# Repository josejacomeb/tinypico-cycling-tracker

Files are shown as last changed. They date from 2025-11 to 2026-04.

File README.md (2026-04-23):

# tinypico-cycling-tracker

Tinypico based GPS + IMU + SD data logger for cycling purposes
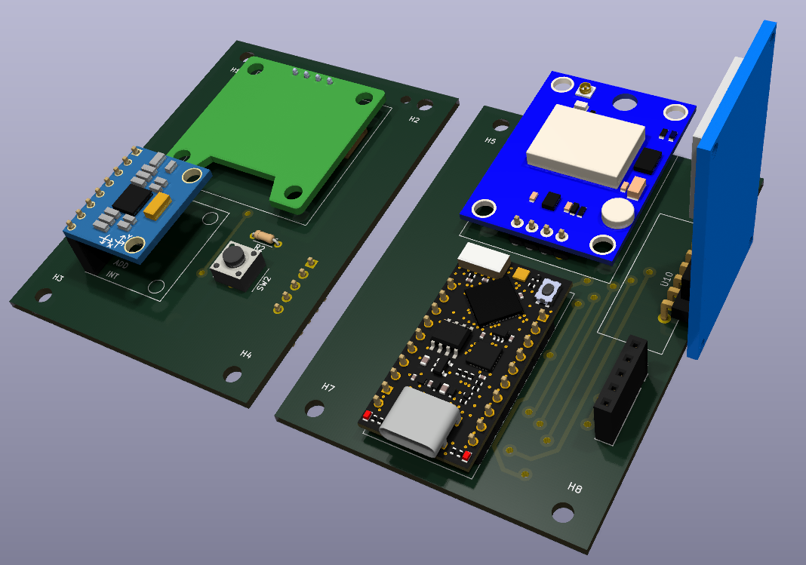
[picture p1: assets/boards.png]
TinyPico Cycling Tracker TinyPICO Cycling Tracker


## Components

### Software

**Programming Languages**: C++20 and Python 3.12

#### Electronic Design

- [Kicad v9.x.x](https://www.kicad.org/)
- [KiKit v1.7.x](https://yaqwsx.github.io/KiKit/latest/)

#### Integrated Development Environment

- [Arduino IDE v2.3.x](https://www.arduino.cc/en/software/)
- [Visual Studio Code](https://code.visualstudio.com/)

#### Software Libraries

- [TinyGPS++](https://github.com/mikalhart/TinyGPSPlus)
- [Electronics Cats MPU6050](https://github.com/ElectronicCats/mpu6050)
- [Embedded_UKF_Library](https://github.com/pronenewbits/Embedded_UKF_Library)
- [Pandas 2.x](https://pandas.pydata.org/)
- [gpxpy](https://github.com/tkrajina/gpxpy)
- [FilterPy v1.4.x](https://filterpy.readthedocs.io/en/latest/#)

### Hardware

- [TinyPICO](https://www.tinypico.com/): An ESP32 Dico D4 based development platform
- [uBlox-Neo6M](https://www.u-blox.com/en/product/neo-6-series): A versatile GPS Module with Antenna
- [Display OLED I2C 0.96" SSD1306](https://soldered.com/product/display-oled-i2c-white-0-96-ssd1306/): An 128x64px 0.96" OLED Display with I2C Communication
- [MPU6050](https://invensense.tdk.com/products/motion-tracking/6-axis/mpu-6050/): An integrated gyroscope and accelerometer with I2C communication
- [MicroSD Card Adapter](https://hobbycomponents.com/adapters/578-microsd-card-adapter-with-level-shifters): A SPI module to interface microcontrollers with a microSD card.

### Communication Protocols

- SPI: SD Card Reader -> TinyPICO
- I2C: OLED Screen & MPU6050 -> TinyPICO
- UART: GPS -> TinyPICO

## Instructions

### For KiCad

1. Add the symbols via the `Preferences` > `Manage symbol Libraries` > `Project Specific Libraries`, make sure that you add the `kicad-libraries` subfolders:

    1. `usini_kicad_sensors/usini_sensors.pretty`
    2. `uBlox-Neo6M/uBLox-NEO-6M.pretty`
    3. `MicroSD-Card-Adapter/MicroSD-Card-Adapter.kicad_sym`
    4. `Soldered-SSD1306-OLED-Display/Soldered.kicad_sym`
    5. `TinyPICO/TinyPICO.kicad_sym`

2. Add the footprints via the `Preferences` > `Manage Footprint Libraries` > `Project Specific Libraries`, make sure that you add the `footprint` subfolders
    1. `usini_kicad_sensors/usini_sensors.kicad_sym`
    2. `uBlox-Neo6M/uBlox-NEO-6M.kicad_sym`
    3. `MicroSD-Card-Adapter/MicroSD-Card-Adapter.kicad_sym`
    4. `Soldered-SSD1306-OLED-Display/Soldered.pretty`
    5. `TinyPICO/TinyPICO.pretty`

3. Install the `KiKit` in your local system

    ```bash
    python -m venv .venv/
    source .venv/bin/activate
    pip3 install kikit
    ```

### For Arduino

#### Run the full prototype

1. Please follow the Espressif [instructions](https://docs.espressif.com/projects/arduino-esp32/en/latest/installing.html) to support the `ESP32` boards on your Arduino.
2. Please install the following libraries in your Arduino IDE in your Tools > Manage Libraries section:
    1. [TinyPICO Helper Library](https://docs.arduino.cc/libraries/tinypico-helper-library/)
    2. [Adafruit SSD1306](https://docs.arduino.cc/libraries/adafruit-ssd1306/)
    3. [TinyGPSPlus](https://docs.arduino.cc/libraries/adafruit-ssd1306/)
3. Select the `UM TinyPICO` board in the Arduino IDE Tools > Board > ESP32
4. Select the Communication Port to `/dev/ttyACM0` if you're running on Linux.
5. Calibrate IMU as shown in the [MPU6050 Zero tutorial](https://github.com/ElectronicCats/mpu6050/wiki/4.-Examples#zero) and copy the offsets to the main code
6. Open the folder [code/arduino-tct/](code/arduino-tct/) with the IDE to flash the code to your TinyPICO Board.

#### Check other software

1. Please refer to the [code README](code/README.md) for more infomation

## Modes

The following screens were converted to `.png`  and later transformed to a compatible data with the help of the Adafruit [make_splash.py](https://github.com/adafruit/Adafruit_SSD1306/blob/master/scripts/make_splash.py) script.

### Loading

Loading Screen

This screen show the loading in realtime of the three peripherals.

### Waiting

Waiting Screen

This is the normal screen you'll see before pushing the start button.

### Recording workout

Recording Screen

After pushing the start button, you will see the elevation, pace, slope, altitude and workout time in the screen.

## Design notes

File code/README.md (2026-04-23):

# Usage

## Cycling Tracker

The TinyPico Ciclying Tracker source code is defined in the [arduino-tct](arduino-tct/) folder

## Data Logger

Flash your device with the code to gather GPS + IMU Data, ready to be used by the Sensor Fusion models.

## Sensor Fusion Implementation

The purpose of the `test_ukf*` are to understand, code and validate the sensor fusion implementation. The final result of the conversion should be a GPX file.

### Python

#### Installation

To install the Python Libraries, please use the use the following commands

    ```bash
    python -m venv .venv
    source .venv/bin/activate
    pip install -r utils/requirements.txt
    ```

#### Sensor Fusion Usage

    ```bash
    usage: sensor_fusion.py [-h] -i INPUT_CSV -o OUTPUT_CSV

    UKF GPS+IMU sensor fusion. Predicts at 10 Hz (IMU rate), updates on GPS fixes (~1 Hz). Outputs a fused position and velocity estimate on every row.

    options:
    -h, --help            show this help message and exit
    -i INPUT_CSV, --input_csv INPUT_CSV
                            Input CSV logged by the TCT at 10 Hz.
    -o OUTPUT_CSV, --output_csv OUTPUT_CSV
                            Path to save the UKF result in CSV.
    ```

## Utils

The `utils`folder contain two useful scripts for the development for this project:

1. `csv_to_gpx`: Converts the data logger generated data to a GPX representation that is equivalent with the output of other devices, such as Garmin or Samsung Health
2. `validate_gpx_performance`: Comparte two GPX files that were generated in the same time and outputs the RMS output and the distance

## Helper Script

To use the python scripts in one command, please use the helper script, it will convert and compare your output `gpx file`

    ```bash
    ./test_sensor_fusion.sh path/to/your/sensor_data.csv path/to/your/gt.gpx
    ```

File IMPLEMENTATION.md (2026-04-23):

# GPS + IMU Sensor Fusion

## The Problem

GPS gives us position but updates slowly and is noisy. The IMU gives us acceleration at high frequency but drifts over time. The goal is to combine both to get a smoother, more accurate position and velocity estimate.

---

## Step 1 — Convert GPS to Metres

The UKF works in metric space. GPS coordinates (degrees) are converted to a **signed distance in metres** from a fixed local origin using the Haversine formula:

$$a = \sin^2\!\left(\frac{\Delta\phi}{2}\right) + \cos\phi_1 \cdot \cos\phi_2 \cdot \sin^2\!\left(\frac{\Delta\lambda}{2}\right)$$

$$d = 2R_E \cdot \text{atan2}\!\left(\sqrt{a},\ \sqrt{1-a}\right)$$

The problem is split into two independent axes — **North** (latitude) and **East** (longitude) — each handled by its own filter.

---

## Step 2 — The State Model

Each filter tracks position and velocity along one axis:

$$\mathbf{x}_k = \begin{bmatrix} p_k \\ v_k \end{bmatrix}$$

The IMU acceleration $a_k$ drives the prediction at each step:

$$p_k = p_{k-1} + v_{k-1}\,\Delta t + \tfrac{1}{2}\,a_k\,\Delta t^2$$
$$v_k = v_{k-1} + a_k\,\Delta t$$

GPS measures position and velocity directly, so the measurement model is simply:

$$\mathbf{z}_k = \begin{bmatrix} p_k \\ v_k \end{bmatrix}$$

---

## Step 3 — The Unscented Kalman Filter

A standard Kalman Filter linearises nonlinear functions. The UKF avoids this by using the **Unscented Transform** — it generates $2n+1$ representative points (sigma points) around the current estimate, propagates each one through the model, and recombines them to recover the new mean and covariance.

With state dimension $n = 2$, this gives **5 sigma points** per step.

### Predict

$$\hat{\mathbf{x}}_{k|k-1},\ \mathbf{P}_{k|k-1} = \text{UnscentedTransform}(f,\ \mathbf{x}_{k-1},\ \mathbf{P}_{k-1}) + \mathbf{Q}$$

### Update (when GPS is available)

$$\mathbf{K}_k = \mathbf{P}_{xz}\,\mathbf{S}_k^{-1}$$

$$\hat{\mathbf{x}}_k = \hat{\mathbf{x}}_{k|k-1} + \mathbf{K}_k\left(\mathbf{z}_k - \hat{\mathbf{z}}_k\right)$$

$$\mathbf{P}_k = \mathbf{P}_{k|k-1} - \mathbf{K}_k\,\mathbf{S}_k\,\mathbf{K}_k^\top$$

The Kalman gain $\mathbf{K}_k$ balances trust between the model prediction and the GPS measurement based on their relative uncertainties.

---

## Step 4 — Noise Matrices

**Process noise Q** — how IMU uncertainty grows over time:

$$\mathbf{Q} = \sigma_a^2 \begin{bmatrix} \dfrac{\Delta t^4}{4} & \dfrac{\Delta t^3}{2} \\[8pt] \dfrac{\Delta t^3}{2} & \Delta t^2 \end{bmatrix}$$

**Measurement noise R** — GPS position and velocity are independent with different accuracies:

$$\mathbf{R} = \begin{bmatrix} \sigma_p^2 & 0 \\ 0 & \sigma_v^2 \end{bmatrix} = \begin{bmatrix} 6.25\ \text{m}^2 & 0 \\ 0 & 0.01\ \text{(m/s)}^2 \end{bmatrix}$$

**Initial covariance** — seeded from the GPS position accuracy at startup:

$$\mathbf{P}_0 = \sigma_p\,\mathbf{I} = \begin{bmatrix} 2.5 & 0 \\ 0 & 2.5 \end{bmatrix}$$

---

## Step 5 — Back to Coordinates

After filtering, the metric estimates $(p_N, p_E)$ are converted back to geographic coordinates using the forward azimuth formula — first applying $p_N$ northward, then $p_E$ eastward from the local origin.

## Inspiration

- [Kalman Filter Practical Walkthrough by Scott Lodbell](https://web.archive.org/web/20200229043952/http://scottlobdell.me/2017/01/gps-accelerometer-sensor-fusion-kalman-filter-practical-walkthrough/)
- [Sensor Fusion implementation in Python by smahajan07](https://github.com/smahajan07/sensor-fusion)
- [The MPU6050 Explained by mjwhite8119](https://mjwhite8119.github.io/Robots/mpu6050)

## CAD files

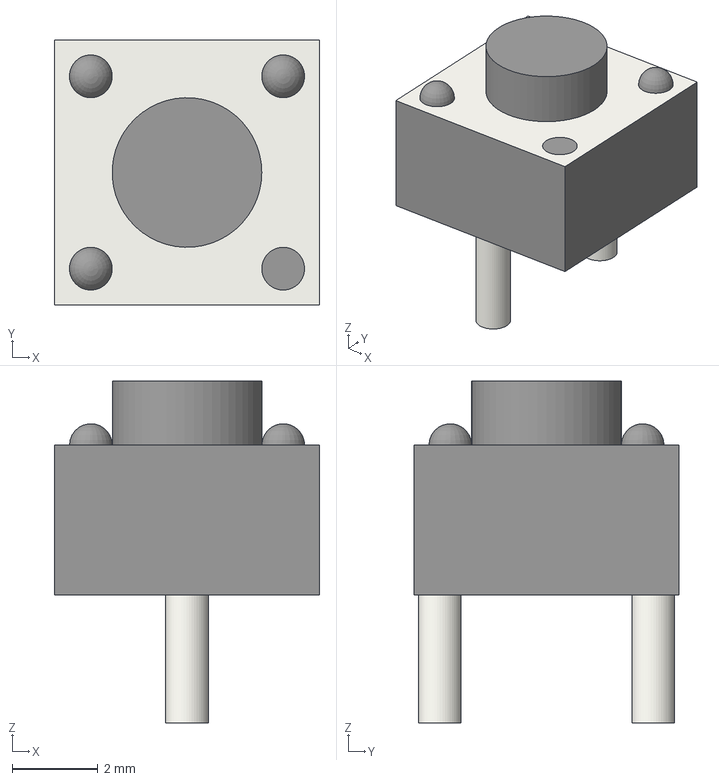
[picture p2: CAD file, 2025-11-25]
Schematics/kicad-libraries/SPST Button/SPST Button.step
6.20 x 6.20 x 8.00 mm

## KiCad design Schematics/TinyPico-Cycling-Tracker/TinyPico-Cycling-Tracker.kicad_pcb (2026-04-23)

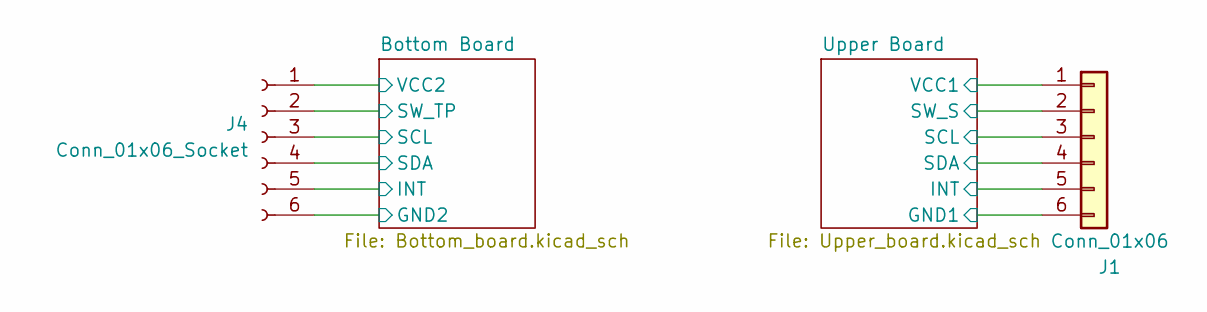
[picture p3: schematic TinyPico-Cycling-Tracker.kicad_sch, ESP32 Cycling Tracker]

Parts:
J1: Conn_01x06; PinHeader_1x06_P2.54mm_Vertical
J4: Conn_01x06_Socket; PinSocket_1x06_P2.54mm_Vertical

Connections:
/Bottom Board/INT: J4.5; also elsewhere on the board
/Bottom Board/SCL: J4.3; also elsewhere on the board
/Bottom Board/SDA: J4.4; also elsewhere on the board
/Bottom Board/SW_TP: J4.2; also elsewhere on the board
/Upper Board/INT: J1.5; also elsewhere on the board
/Upper Board/SCL: J1.3; also elsewhere on the board
/Upper Board/SDA: J1.4; also elsewhere on the board
/Upper Board/SW_S: J1.2; also elsewhere on the board
GND1: J1.6; also elsewhere on the board
GND2: J4.6; also elsewhere on the board
VCC1: J1.1; also elsewhere on the board
VCC2: J4.1; also elsewhere on the board

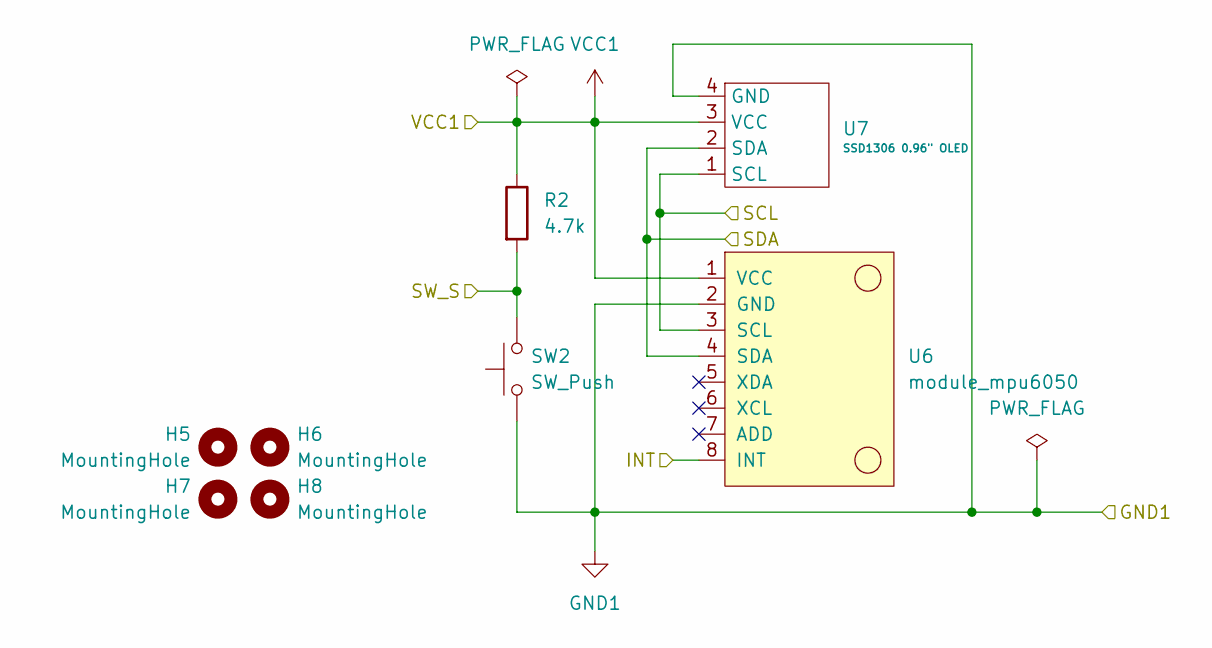
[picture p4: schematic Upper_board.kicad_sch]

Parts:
H5, H6, H7, H8: MountingHole; MountingHole_3mm
R2: 4.7k; R_Axial_DIN0204_L3.6mm_D1.6mm_P5.08mm_Horizontal
SW2: SW_Push; SPST_Button
U6: module_mpu6050
U7: SSD1306 0.96" OLED; Soldered-Ssd1306-OLED

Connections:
/Upper Board/INT: U6.8 (INT); also elsewhere on the board
/Upper Board/SCL: U6.3 (SCL), U7.1 (SCL); also elsewhere on the board
/Upper Board/SDA: U6.4 (SDA), U7.2 (SDA); also elsewhere on the board
/Upper Board/SW_S: R2.2, SW2.2; also elsewhere on the board
GND1: SW2.1, U6.2 (GND), U7.4 (GND); also elsewhere on the board
VCC1: R2.1, U6.1 (VCC), U7.3 (VCC); also elsewhere on the board

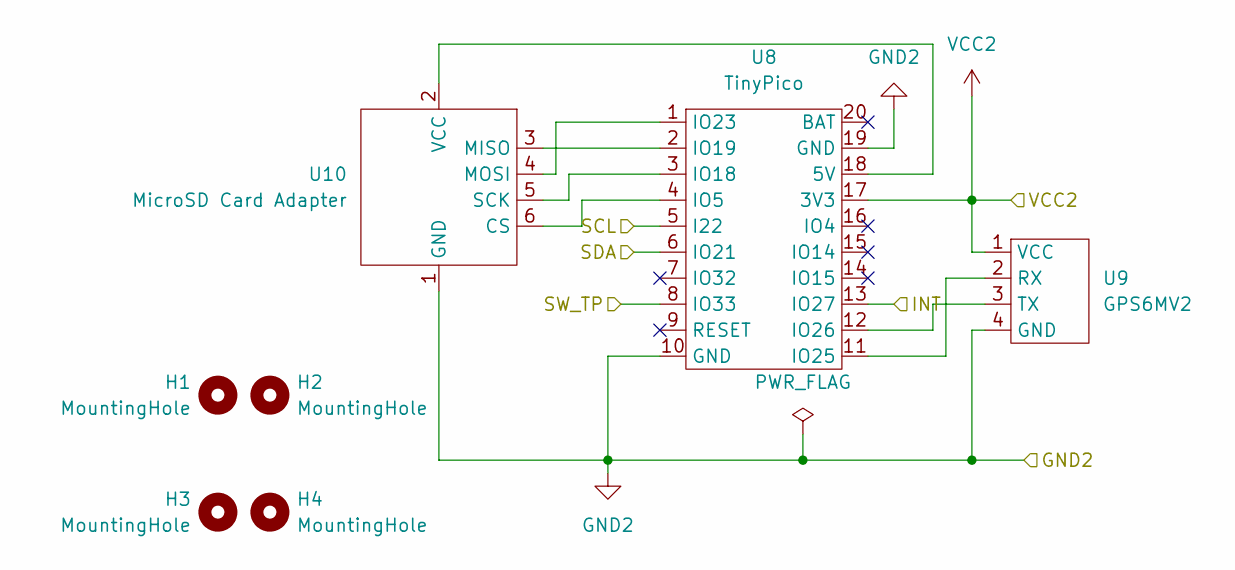
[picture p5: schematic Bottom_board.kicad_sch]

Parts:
H1, H2, H3, H4: MountingHole; MountingHole_3mm
U8: TinyPico; TinyPICO_V2_USBC
U9: GPS6MV2; uBlox-NEO-6M
U10: MicroSD Card Adapter; MicroSD-Card-Adapter

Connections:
/Bottom Board/INT: U8.13 (IO27); also elsewhere on the board
/Bottom Board/SCL: U8.5 (I22); also elsewhere on the board
/Bottom Board/SDA: U8.6 (IO21); also elsewhere on the board
/Bottom Board/SW_TP: U8.8 (IO33); also elsewhere on the board
GND2: U8.10 (GND), U8.19 (GND), U9.4 (GND), U10.1 (GND); also elsewhere on the board
unnamed: U8.11 (IO25), U9.2 (RX)
unnamed: U8.12 (IO26), U9.3 (TX)
unnamed: U8.4 (IO5), U10.6 (CS)
unnamed: U8.2 (IO19), U10.3 (MISO)
unnamed: U8.1 (IO23), U10.4 (MOSI)
unnamed: U8.3 (IO18), U10.5 (SCK)
unnamed: U8.18 (5V), U10.2 (VCC)
VCC2: U8.17 (3V3), U9.1 (VCC); also elsewhere on the board

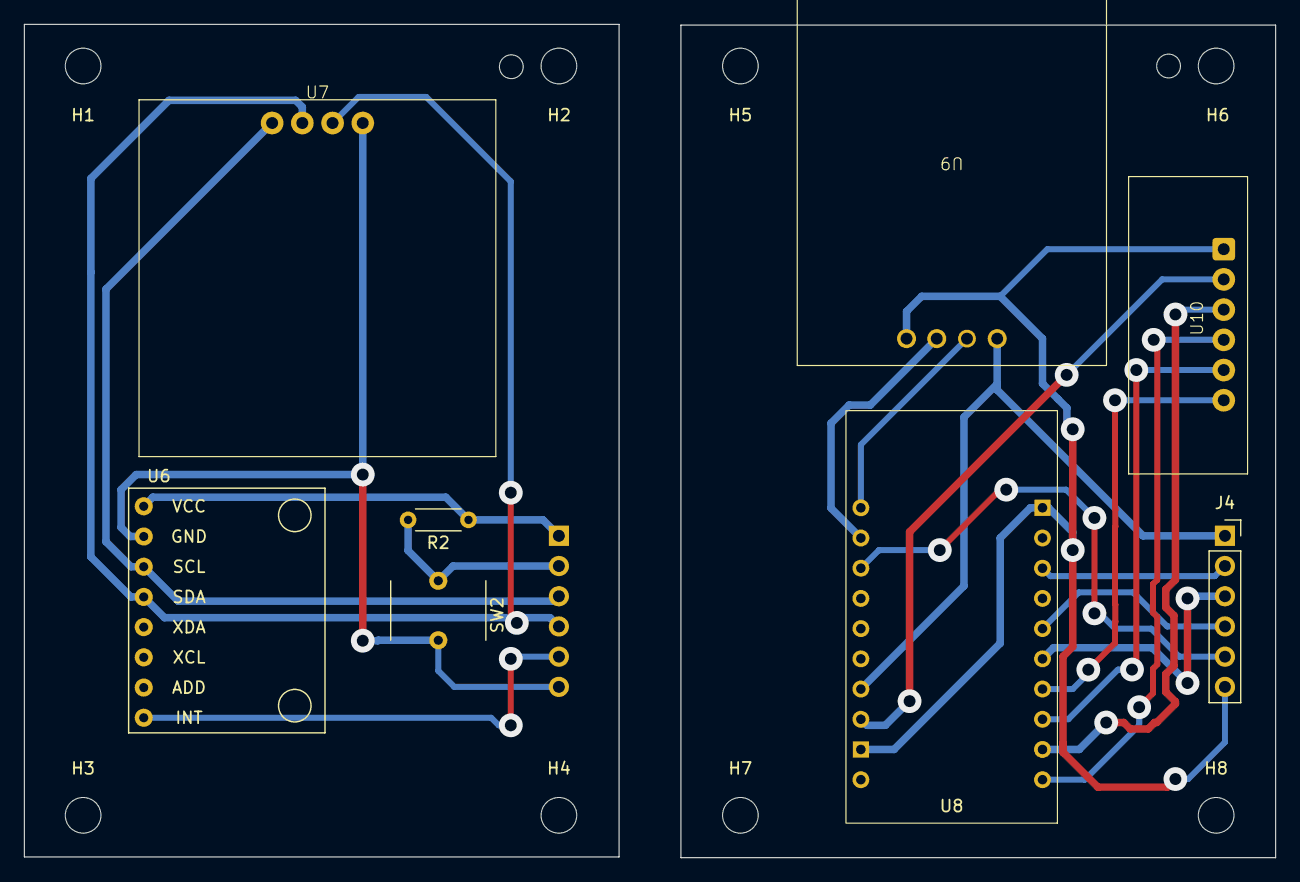
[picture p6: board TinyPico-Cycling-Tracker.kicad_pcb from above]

Board: 2 copper layers, 105.2 x 70.1 mm, 17 parts (1 on the bottom side), 19 nets.

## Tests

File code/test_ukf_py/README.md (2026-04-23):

# Sensor Fusion in Python

Implementation of the Unscented Kalman Filter(UKF) with accessible sensors such as `uBlox-Neo6M` and `MPU6050`, the scripts expect a `.csv`, consider to use the [data-logger](../data_logger/) to get the formatted data.

## Installation

1. Create a new python venv with:

    ```bash
    python -m venv .venv/
    ```

2. Source your new venv, for example in Linux

    ```bash
    source .venv/bin/activate
    ```

3. Install the prerequisites with

    ```bash
    pip install -r requirements.txt
    ```

## Usage

```bash
python3 sensor_fusion.py --help
usage: sensor_fusion.py [-h] -i INPUT_CSV -o OUTPUT_CSV

Test UKF GPS+IMU sensor fusion with CSV data.

options:
  -h, --help            show this help message and exit
  -i INPUT_CSV, --input_csv INPUT_CSV
                        Path to the input CSV file with GPS and IMU data.
  -o OUTPUT_CSV, --output_csv OUTPUT_CSV
                        Path to the Fused output CSV file.
```

## Structure

```bash
├── constants.py
├── data_types.py
├── ukf_gps_imu_graphics.ipynb
├── README.md
├── requirements.txt
├── sensor_fusion.py
├── ukf_gps_imu.py
└── utils.py
```

## Files

- `constants.py`: UKF, Accelerometer and GPS constants
- `data_types.py`: Data types used in the project
- `ukf_gps_imu.py`: Implementation of the sensor fusion GPS + IMU with UKF with filterpy
- `sensor_fusion.py`: Simulation of a real implementation that should be in the microcontroller
- `ukf_gps_imu_graphics.ipynb`: Data visualisation for comparison

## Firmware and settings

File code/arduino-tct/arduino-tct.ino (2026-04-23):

/*
* Software for the Tinypico GPS Tracker
* Written by: josejacomeb / 2025
*/
#include <I2Cdev.h>
#include <MPU6050_6Axis_MotionApps612.h>  // For get no gravity results
#include <SPI.h>
#include <TinyGPS++.h>
#include <TinyPICO.h>

#include "data_types.hpp"
#include "oled.hpp"
#include "ukf_gps_imu.hpp"
#include "writter.hpp"
#include "workout.hpp"

// Debug mode
#define DEBUG 0

// Initialise the TinyPICO library
TinyPICO tp = TinyPICO();

// ---- MPU6050 Control/Status Variables ----
bool DMPReady = false;   // Set true if DMP init was successful
uint8_t MPUIntStatus;    // Holds actual interrupt status byte from MPU
uint8_t devStatus;       // Return status after each device operation (0 = success, !0 = error)
uint16_t packetSize;     // Expected DMP packet size (default is 42 bytes)
uint8_t FIFOBuffer[64];  // FIFO storage buffer

// ---- Orientation/Motion Variables ----
Quaternion q;         // [w, x, y, z] Quaternion container
VectorInt16 aa;       // [x, y, z]            Accel sensor measurements
VectorInt16 gy;       // [x, y, z]            Gyro sensor measurements
VectorInt16 aaReal;   // [x, y, z]            Gravity-free accel sensor measurements
VectorInt16 aaWorld;  // [x, y, z]            World-frame accel sensor measurements
VectorFloat gravity;  // [x, y, z]            Gravity vector
float ypr[3];         // [yaw, pitch, roll] Yaw/Pitch/Roll container and gravity vector
MPU6050 mpu;

// ---- Interrupt detection routine ----
volatile bool MPUInterrupt = false;  // Indicates whether MPU6050 interrupt pin has gone high

void DMPDataReady() {
  MPUInterrupt = true;
}

// ---- GPS Variables ----
TinyGPSPlus gps;
double speed_m_s, altitude;
unsigned long start;
const unsigned int period = 16;
unsigned int display_results_counter = 1;
const unsigned int max_display_results_counter = 60;

// ---- Application Objects ----
OLEDGPS oled_display;
Workout workout;

// ---- State Machine ----
enum class State {
  LOADING,
  WAITING,
  START_WORKOUT,
  END_WORKOUT,
  SUMMARY
};

State m_state;
double vNorth, vEast;
UKFGPSIMU sf_lat, sf_lng;

const unsigned int led_time = 5000;

struct LatLonDeg getPointAhead(
  const LatLonDeg& start,
  double distance_m,
  double bearing_deg) {

  double lat1 = start.lat * M_PI / 180.0;
  double lon1 = start.lon * M_PI / 180.0;
  double bearing = bearing_deg * M_PI / 180.0;
  double delta = distance_m / EARTH_RADIUS;

  double lat2 = asin(
    sin(lat1) * cos(delta) + cos(lat1) * sin(delta) * cos(bearing));

  double y = sin(bearing) * sin(delta) * cos(lat1);
  double x = cos(delta) - sin(lat1) * sin(lat2);

  double lon2 = lon1 + atan2(y, x);

  LatLonDeg result;
  result.lat = lat2 * 180.0 / M_PI;
  result.lon = lon2 * 180.0 / M_PI;

  return result;
}
LatLonDeg ZeroPoint, PointEast, PointNorthEast;

void setup() {
  tp.DotStar_Clear();
  tp.DotStar_SetPixelColor(242, 57, 29);
  tp.DotStar_Show();
  pinMode(INPUT_PIN, INPUT);
  // Used for debug output only
  Serial.begin(115200);
  oled_display.init_screen();
  // Using I2CDEV_ARDUINO_WIRE
  Wire.begin();
  Wire.setClock(400000);  // 400kHz I2C clock. Comment on this line if having compilation difficulties
  /*Initialize device*/
  Serial.println(F("Initializing I2C devices..."));
  mpu.initialize();
  pinMode(INTERRUPT_PIN, INPUT);
  Serial.println("Initializing SD card...");
  if (!SD.begin(CS)) {
    Serial.println("SD initialization failed!");
    while (1)
      ;
  }
  oled_display.init_sd();
  delay(led_time);
  /*Verify connection*/
  Serial.println(F("Testing MPU6050 connection..."));
  if (mpu.testConnection() == false) {
    Serial.println("MPU6050 connection failed");
    while (true)
      ;
  } else {
    Serial.println("MPU6050 connection successful");
  }

  /* Initializate and configure the DMP*/
  Serial.println(F("Initializing DMP..."));
  devStatus = mpu.dmpInitialize();

  // Calibration values defined in the constants.hpp
  mpu.setXAccelOffset(XAccelOffset);
  mpu.setYAccelOffset(YAccelOffset);
  mpu.setZAccelOffset(ZAccelOffset);
  mpu.setXGyroOffset(XGyroOffset);
  mpu.setYGyroOffset(YGyroOffset);
  mpu.setZGyroOffset(ZGyroOffset);
  
  /* Making sure it worked (returns 0 if so) */
  if (devStatus == 0) {
    Serial.println(F("Enabling DMP..."));  //Turning ON DMP
    mpu.setDMPEnabled(true);

    /*Enable Arduino interrupt detection*/
    Serial.print(F("Enabling interrupt detection (Arduino external interrupt "));
    Serial.print(digitalPinToInterrupt(INTERRUPT_PIN));
    Serial.println(F(")..."));
    attachInterrupt(digitalPinToInterrupt(INTERRUPT_PIN), DMPDataReady, RISING);
    MPUIntStatus = mpu.getIntStatus();

    /* Set the DMP Ready flag so the main loop() function knows it is okay to use it */
    Serial.println(F("DMP ready! Waiting for first interrupt..."));
    DMPReady = true;
    packetSize = mpu.dmpGetFIFOPacketSize();  //Get expected DMP packet size for later comparison
  } else {
    Serial.print(F("DMP Initialization failed (code "));  //Print the error code
    Serial.print(devStatus);
    Serial.println(F(")"));
  }
  oled_display.init_imu();
  tp.DotStar_Clear();
  tp.DotStar_SetPixelColor(237, 230, 21);
  tp.DotStar_Show();
  delay(led_time);
  Serial2.begin(9600, SERIAL_8N1, RX, TX);
  Serial.println("Starting Serial 2...");
  while (!gps.location.isValid()) {
    while (Serial2.available() > 0) {
      gps.encode(Serial2.read());
    }
  }
  oled_display.init_gps();
  tp.DotStar_Clear();
  tp.DotStar_SetPixelColor(136, 237, 21);
  tp.DotStar_Show();
  delay(led_time);
  tp.DotStar_SetPower(false);
  m_state = State::WAITING;
  sf_lat.init(GPSAxis::LATITUDE);
  sf_lng.init(GPSAxis::LONGITUDE);
  start = millis();
}

void loop() {
  if (!digitalRead(INPUT_PIN)) {
    delay(500);
    if (digitalRead(INPUT_PIN)) {
      if (m_state != State::START_WORKOUT) {
        workout.start();
        m_state = State::START_WORKOUT;
        write_header(gps);
      } else {
        workout.end();
        m_state = State::END_WORKOUT;
      }
    }
  }
  // Cycle the DotStar LED colour every 25 milliseconds
  if (!DMPReady) return;  // Stop the program if DMP programming fails.
  /* Read a packet from FIFO */
  if (mpu.dmpGetCurrentFIFOPacket(FIFOBuffer)) {  // Get the Latest packet
    /* Display Euler angles in degrees */
    mpu.dmpGetQuaternion(&q, FIFOBuffer);
    mpu.dmpGetAccel(&aa, FIFOBuffer);
    mpu.dmpGetGravity(&gravity, &q);
    mpu.dmpGetLinearAccel(&aaReal, &aa, &gravity);
    mpu.dmpGetLinearAccelInWorld(&aaWorld, &aaReal, &q);
    mpu.dmpGetYawPitchRoll(ypr, &q, &gravity);
    // As located in the PCB
    sf_lat.add_imu_acceleration(aaWorld.y);
    sf_lng.add_imu_acceleration(aaWorld.x);
  }
  while (Serial2.available() > 0) {
    gps.encode(Serial2.read());
    if (gps.location.isUpdated() && gps.location.isValid()) {
      altitude = gps.altitude.isValid() ? gps.altitude.meters() : 0.0;
      speed_m_s = gps.speed.isValid() ? gps.speed.mps() : 0.0;
      vNorth = speed_m_s * cos(gps.course.deg() * M_PI / 180);
      vEast = speed_m_s * sin(gps.course.deg() * M_PI / 180);
      unsigned long ts = millis();
      // distance accumulation
      if (workout.is_last_pos_valid()) {
        double d = workout.haversine(workout.get_last_location(), gps.location);
        // ignore spurious large jumps
        if (d < 50.0) {
          if (m_state == State::START_WORKOUT)
            workout.add_distance(d);
        }
      }
      workout.pushWP(gps.location, altitude);
      double speed_kmh = speed_m_s * 3.6;
      sf_lat.add_gps_position_velocity(gps.location, vNorth);
      sf_lng.add_gps_position_velocity(gps.location, vEast);
    }
  }
  // Calculation of the final position
  PointEast = getPointAhead(ZeroPoint, sf_lat.get_predicted_position_meters(), 270);
  PointNorthEast = getPointAhead(PointEast, sf_lng.get_predicted_position_meters(), 180);

  if (millis() - start > period) {
#if DEBUG
    Serial.print("YPR Rad: ");
    Serial.print(ypr[0]);
    Serial.print(", ");
    Serial.print(ypr[1]);
    Serial.print(", ");
    Serial.print(ypr[2]);
    Serial.print(" Lat: ");
    Serial.print(gps.location.lat(), 6);
    Serial.print(" Lng: ");
    Serial.print(gps.location.lng(), 6);
    Serial.print(" speed: ");
    Serial.print(speed);
    Serial.print(" altitude: ");
    Serial.print(altitude);
    Serial.print(" Time in UTC: ");
    Serial.println(String(gps.date.year()) + "/" + String(gps.date.month()) + "/" + String(gps.date.day()) + "," + String(gps.time.hour()) + ":" + String(gps.time.minute()) + ":" + String(gps.time.second()));
#endif
    switch (m_state) {
      case State::WAITING:
        oled_display.draw_wait_screen(gps.time);
        break;
      case State::START_WORKOUT:
        oled_display.update_values(workout.get_total_distance(), workout.get_slope(ypr[1]), workout.paceFromSpeed(speed_m_s), altitude, workout.get_elapsed_workout_time());
        write_gpx(PointNorthEast, altitude, gps.date, gps.time);
        break;
      case State::END_WORKOUT:
        write_file(trk_end_tag);
        write_file(trk_end_segm);
        write_file("</gpx>");
        m_state = State::SUMMARY;
        break;
      case State::SUMMARY:
        display_results_counter++;
        oled_display.display_total_results(workout.get_total_distance(), workout.get_total_ms());
        if (display_results_counter > max_display_results_counter) {
          display_results_counter = 1;
          m_state = State::WAITING;
        }
        break;
    }
    start = millis();
  }
}

void SPEW_THE_ERROR(char const* str) {
#if (SYSTEM_IMPLEMENTATION == SYSTEM_IMPLEMENTATION_PC)
  cout << (str) << endl;
#elif (SYSTEM_IMPLEMENTATION == SYSTEM_IMPLEMENTATION_EMBEDDED_ARDUINO)
  Serial.println(str);
#else
  /* Silent function */
#endif
  while (1)
    ;
}

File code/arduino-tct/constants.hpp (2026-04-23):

#pragma once
#include <math.h>

// TinyPICO PINS
// Digital UART Pins for ESP32-PICO-D4
#define TX 25
#define RX 26
// Push Button Pin
#define INPUT_PIN 33
// SD Pins control
#define CS 5
// MPU Interrupt Pin
#define INTERRUPT_PIN 27
// APA102 Dotstar
#define DOTSTAR_PWR 13
#define DOTSTAR_DATA 2  // Internal TinyPICO wiring — do not drive manually
#define DOTSTAR_CLK 12

const double EARTH_RADIUS = 6371 * 1000.0;  // Meters
const float deg_2_rad_const = M_PI / 180.0f;

// This constant is MPU6050 raw ADC counts per 1g at ±2g full scale (from datasheet).
// Dividing raw counts by LSB_PER_G gives acceleration in units of g, NOT m/s².
// To convert to m/s², also multiply by SURFACE_GRAVITY:
// float acc_ms2 = (raw_counts / (float)LSB_PER_G) * SURFACE_GRAVITY;
const float LSB_PER_G = 16384.0f;

const float SURFACE_GRAVITY = 9.771927346f;  // At Ecuador, ~2,729 m altitude

/* ================================================== The AHRS/IMU variables ================================================== */
/* Gravity vector constant (align with global Z-axis) */
#define IMU_ACC_Z0 (1)

/* UKF initialization constant -------------------------------------------------------------------------------------- */
#define P_INIT (2.5f)                            // uBlox 6M horizontal position accuracy (meters), used to seed UKF covariance
const float Rv_INIT = (1e-3 * SURFACE_GRAVITY);  // Calibration Tolerance
#define Rn_INIT_ACC (0.0015f)

/* Supply your gyro offsets here, scaled for min sensitivity */
// Please see: https://github.com/ElectronicCats/mpu6050/blob/master/examples/IMU_Zero/IMU_Zero.ino
const int16_t XAccelOffset = -260;
const int16_t YAccelOffset = -2088;
const int16_t ZAccelOffset = 1588;
const int16_t XGyroOffset = -143;
const int16_t YGyroOffset = -3;
const int16_t ZGyroOffset = -331;

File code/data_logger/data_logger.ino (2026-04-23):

/*
* Data Logger for the TinyPico Cycling Tracker
* Retrieves data from GPS, IMU and saves data into a .csv file
* Written by: josejacomeb / 2025
*/

#include <I2Cdev.h>
#include <MPU6050_6Axis_MotionApps612.h>
#include <SPI.h>
#include <TinyGPS++.h>
#include <TinyPICO.h>

#include "constants.hpp"
#include "konfig.h"
#include "writer.hpp"

// See the data in the Arduino Serial Plotter https://docs.arduino.cc/software/ide-v2/tutorials/ide-v2-serial-plotter/
#define SERIAL_PLOTTER 0

const unsigned int led_time = 1000;
double speed_m_s, altitude, latitude, longitude, vNorth, vEast, course_rad, course_deg;
unsigned long start, wait_time, elapsed_time, start_time, now;
// Acceleration in m/s² (converted from raw DMP counts at read time).
// Using float keeps units consistent with vNorth/vEast (m/s) in the CSV.
float accNorth, accEast;
float elapsed_seconds;

// ---- Yaw offset (DMP world frame → geographic North/East) ----
// The DMP world frame X/Y is gravity-aligned but its "North" is arbitrary
// (it points wherever the sensor was facing at power-on).
// Once GPS reports a reliable course we compute a one-shot rotation offset
// so that aaWorld can be correctly decomposed into geographic North/East.
float yawOffsetRad = 0.0f;
bool yawCalibrated = false;

// Initialise the TinyPICO library
TinyPICO tp = TinyPICO();

// ---- MPU6050 Control/Status Variables ----
bool DMPReady = false;   // Set true if DMP init was successful
uint8_t MPUIntStatus;    // Holds actual interrupt status byte from MPU
uint8_t devStatus;       // Return status after each device operation (0 = success, !0 = error)
uint16_t packetSize;     // Expected DMP packet size (default is 42 bytes)
uint8_t FIFOBuffer[64];  // FIFO storage buffer

// ---- Orientation/Motion Variables ----
Quaternion q;         // [w, x, y, z] Quaternion container
VectorInt16 aa;       // [x, y, z]            Accel sensor measurements
VectorInt16 gy;       // [x, y, z]            Gyro sensor measurements
VectorInt16 aaReal;   // [x, y, z]            Gravity-free accel sensor measurements
VectorInt16 aaWorld;  // [x, y, z]            World-frame accel sensor measurements
VectorFloat gravity;  // [x, y, z]            Gravity vector
float ypr[3];         // [yaw, pitch, roll] Yaw/Pitch/Roll container and gravity vector
MPU6050 mpu;

// ---- Interrupt detection routine ----
volatile bool MPUInterrupt = false;  // Indicates whether MPU6050 interrupt pin has gone high

void DMPDataReady() {
  MPUInterrupt = true;
}

// ---- GPS Variables ----
TinyGPSPlus gps;

bool start_writing = false;
const char *extension = "csv";
const char *header_data = "time,alt,lat,lng,vNorth,vEast,accNorth,accEast,gpsUpdate";
// GPS columns (lat, lng, vNorth, vEast, alt) contain NaN when no GPS fix
char buffer[128];

// GPS fields written as NaN when no fix arrives in the current 20 ms cycle.
// IMU acceleration is always valid and written every cycle.
bool gps_updated_this_cycle = false;

// GPS acquisition timeout to avoid hanging forever in setup().
const unsigned long GPS_TIMEOUT_MS = 300000UL;  // 5 minutes

// ---- Yaw offset helpers ----

// Extract yaw angle (radians) from the DMP quaternion (ZYX convention).
float quatToYaw(Quaternion &q) {
  return atan2(2.0f * (q.x * q.y + q.w * q.z),
               q.w * q.w + q.x * q.x - q.y * q.y - q.z * q.z);
}

// Rotate 2-D vector (x, y) counter-clockwise by theta radians.
void rotate2D(float x, float y, float theta, float &xOut, float &yOut) {
  xOut = x * cos(theta) - y * sin(theta);
  yOut = x * sin(theta) + y * cos(theta);
}

void setup() {
  tp.DotStar_Clear();
  tp.DotStar_SetPixelColor(242, 57, 29);
  tp.DotStar_Show();
  // Button should connect INPUT_PIN to GND when pressed (active-low logic).
  pinMode(INPUT_PIN, INPUT_PULLUP);
  // Used for debug output only
  Serial.begin(115200);
  // Using I2CDEV_ARDUINO_WIRE
  Wire.begin();
  Wire.setClock(400000);  // 400kHz I2C clock. Comment on this line if having compilation difficulties
  Serial.println(F("Initializing I2C devices..."));
  mpu.initialize();
  /*Initialize device*/
  pinMode(INTERRUPT_PIN, INPUT);
  Serial.println("Initializing SD card...");
  if (!SD.begin(CS)) {
    Serial.println("SD initialization failed!");
    while (1)
      ;
  }
  delay(led_time);
  /*Verify connection*/
  Serial.println(F("Testing MPU6050 connection..."));
  if (mpu.testConnection() == false) {
    Serial.println("MPU6050 connection failed");
    while (true)
      ;
  } else {
    Serial.println("MPU6050 connection successful");
  }

  /* Initializate and configure the DMP*/
  Serial.println(F("Initializing DMP..."));
  devStatus = mpu.dmpInitialize();

  // Calibration values defined in the constants.hpp
  mpu.setXAccelOffset(XAccelOffset);
  mpu.setYAccelOffset(YAccelOffset);
  mpu.setZAccelOffset(ZAccelOffset);
  mpu.setXGyroOffset(XGyroOffset);
  mpu.setYGyroOffset(YGyroOffset);
  mpu.setZGyroOffset(ZGyroOffset);

  /* Making sure it worked (returns 0 if so) */
  if (devStatus == 0) {
    Serial.println(F("Enabling DMP..."));  //Turning ON DMP
    mpu.setDMPEnabled(true);

    /*Enable Arduino interrupt detection*/
    Serial.print(F("Enabling interrupt detection (Arduino external interrupt "));
    Serial.print(digitalPinToInterrupt(INTERRUPT_PIN));
    Serial.println(F(")..."));
    attachInterrupt(digitalPinToInterrupt(INTERRUPT_PIN), DMPDataReady, RISING);
    MPUIntStatus = mpu.getIntStatus();

    /* Set the DMP Ready flag so the main loop() function knows it is okay to use it */
    Serial.println(F("DMP ready! Waiting for first interrupt..."));
    DMPReady = true;
    packetSize = mpu.dmpGetFIFOPacketSize();  //Get expected DMP packet size for later comparison
  } else {
    Serial.print(F("DMP Initialization failed (code "));  //Print the error code
    Serial.print(devStatus);
    Serial.println(F(")"));
  }
  tp.DotStar_Clear();
  tp.DotStar_SetPixelColor(237, 230, 21);
  tp.DotStar_Show();
  delay(led_time);
  Serial2.begin(9600, SERIAL_8N1, RX, TX);
  Serial.println("Starting Serial 2...");

  // DotStar blinks orange during GPS search; turns green on fix.
  unsigned long gps_wait_start = millis();
  bool blink_state = false;
  Serial.println("Waiting for GPS fix...");
  unsigned long gps_blink_start = millis();
  unsigned long gps_timeout_start = millis();
  while (!gps.location.isValid()) {
    while (Serial2.available() > 0) {
      gps.encode(Serial2.read());
    }
    // Blink orange to show we're waiting
    if (millis() - gps_blink_start > 500) {
      blink_state = !blink_state;
      if (blink_state) tp.DotStar_SetPixelColor(237, 180, 21);
      else tp.DotStar_Clear();
      tp.DotStar_Show();
      gps_blink_start = millis();
    }
    // Timeout — allow device to continue without GPS fix
    if (millis() - gps_timeout_start > GPS_TIMEOUT_MS) {
      Serial.println("GPS timeout — continuing without fix.");
      break;
    }
  }
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

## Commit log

2025-11-17 chore: add IMU footprints
2025-11-18 chore: add custom uBlox-Neo6m footprint
2025-11-20 chore: load schematic with symbols
2025-11-20 chore: initial schematic files
    [TinyPico-Cycling-Tracker.kicad_sch]
2025-11-20 fix: use 5V power pin only
    [TinyPico-Cycling-Tracker.kicad_sch]
2025-11-21 chore: use multisheet for the schematic
    [Bottom_board.kicad_sch, TinyPico-Cycling-Tracker.kicad_sch, Upper_board.kicad_sch]
2025-11-21 chore: add double PCB design
    [TinyPico-Cycling-Tracker.kicad_pcb]
2025-11-23 chore: add two pin SPST button
    [SPST Button.step, TinyPico-Cycling-Tracker.kicad_pcb]
2025-11-23 chore: update PCB to recude the vias
    [Upper_board.kicad_sch]
2025-11-24 chore: move upper board pcb
    [TinyPico-Cycling-Tracker.kicad_pcb]
2025-11-24 fix: down PCB to use less vias
    [TinyPico-Cycling-Tracker.kicad_pcb]
2025-11-27 fix: display initialization in the .hpp file
    [arduino-tct.ino]
2025-11-27 chore: splash screen & base methods - add a splash screen - Add indicators of available sensors - use base methods to manage the OLED
2025-11-30 chore: switch between altitude and elapsed time
2025-11-30 chore: Serial print only in debug mode
2025-11-30 fix: avoid flickering when recording
    [arduino-tct.ino]
2025-11-30 fix: move physical pin to the schematic
    [Bottom_board.kicad_sch]
2025-11-30 chore: position of Push Button & Mounting Holes
    [Bottom_board.kicad_sch, TinyPico-Cycling-Tracker.kicad_pcb, Upper_board.kicad_sch]
2025-12-05 fix: summary page & states - Add a enum to manage the states - Fix the issue with the temporary summary page
    [arduino-tct.ino]
2025-12-16 chore: clean up unused variables and enable LED again
2025-12-29 fix: calculation of the longitude
    [arduino-tct.ino]
2025-12-29 chore: calibrate MPU6050 & instructions fixes #17
    [arduino-tct.ino, constants.hpp]
2025-12-29 fix: calibration data types and use calibrated values
    [arduino-tct.ino, constants.hpp]
2026-01-01 chore: calculate the sensor fusion from the raw sensor data
2026-01-01 fix: name of the csv header row
    [main.cpp]
2026-01-18 chore: Add Python Sensor Fusion UKF
2026-01-18 chore: convert original sensor data for comparison
2026-03-01 fix: typo in the writter name
    [writer.cpp]
2026-03-02 chore: improve data logging & IMU calibration
2026-03-15 chore: improve IMU implementation
2026-03-15 chore: updated sensor fusion implementation
2026-03-15 chore: correct velocities and add altitude
2026-03-23 chore: processing on update - Use the new `gpsUpdate` variable to calculate the Update - Fix the direction of the output - Avoid to use same GPS value in case that is too near
2026-04-03 chore: use interrupt and calibrate
2026-04-04 chore: INT in schematic and PCB
    [Bottom_board.kicad_sch, TinyPico-Cycling-Tracker.kicad_pcb, TinyPico-Cycling-Tracker.kicad_sch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]
2026-04-04 fix: vias warnings
    [TinyPico-Cycling-Tracker.kicad_pcb]
